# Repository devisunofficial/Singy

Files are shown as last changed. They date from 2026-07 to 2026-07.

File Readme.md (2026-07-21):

# Singy

This is an mp3 player I build because I wanted a mp3 player because having an MP3 player seems cool but not wanted to buy one.
It is inspired from iPod but it is not that good(I never had iPod). I just find Screen and Circular Controller a nice design.

### Features:

 - Minimilist. Just a display and Trackpad
 - 2.8 inch non touch display
 - Circular trackpad (but no haptics) {for me adding haptics is too much}
 - Have Wifi, Bluetooth and 3.5mm Headphone Jack (but I will only use 3.5mm Jack)
 - Inbuilt DAC and AMP (I hope it has good sound quality)

### CAD Model:
Everything fits together using Glue.

It has 3 separate printed pieces. The BackPanel, the shell , and Front Panel to cover electronics.
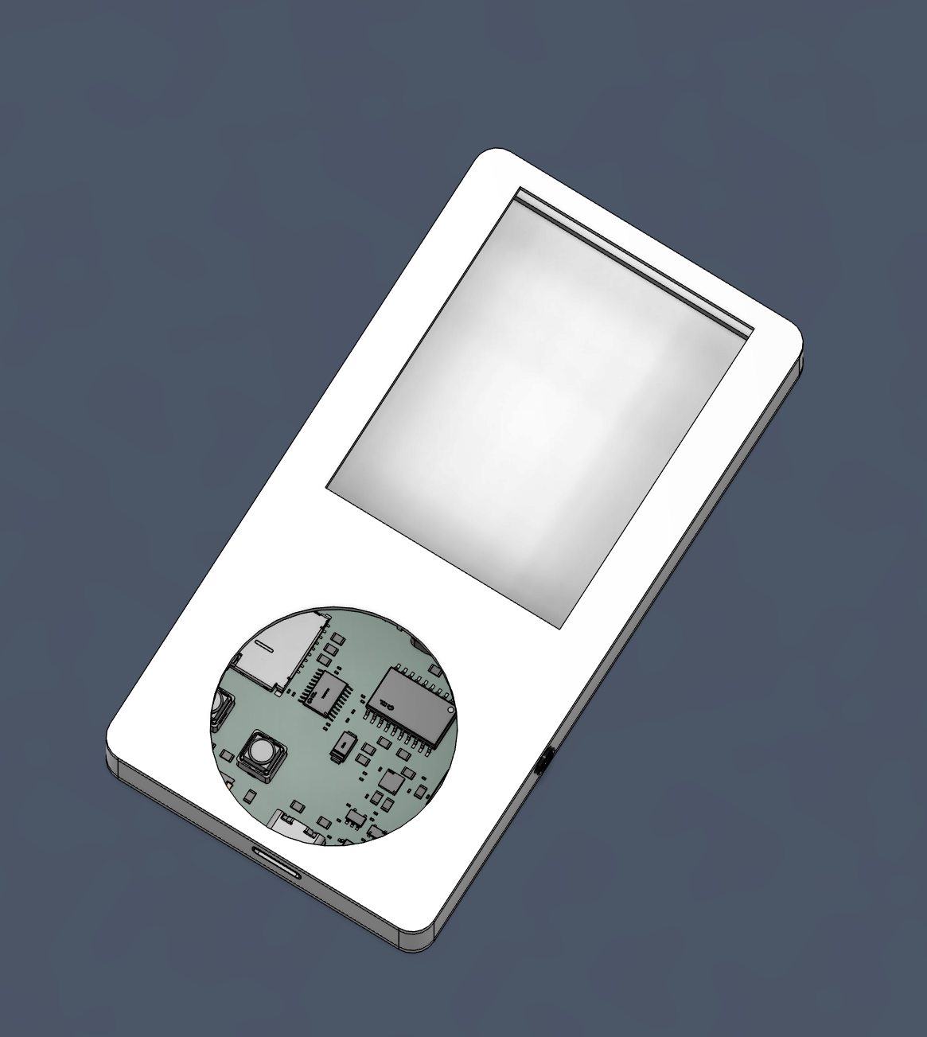
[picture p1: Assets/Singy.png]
Complete Singy


Made in Autodesk Fusion.
I didn't inserted 3D model for Display and Trackpad (Because I can't find)
So I will add this when it is completed!!

### PCB:
Here's my PCB! It was made in KiCad. 

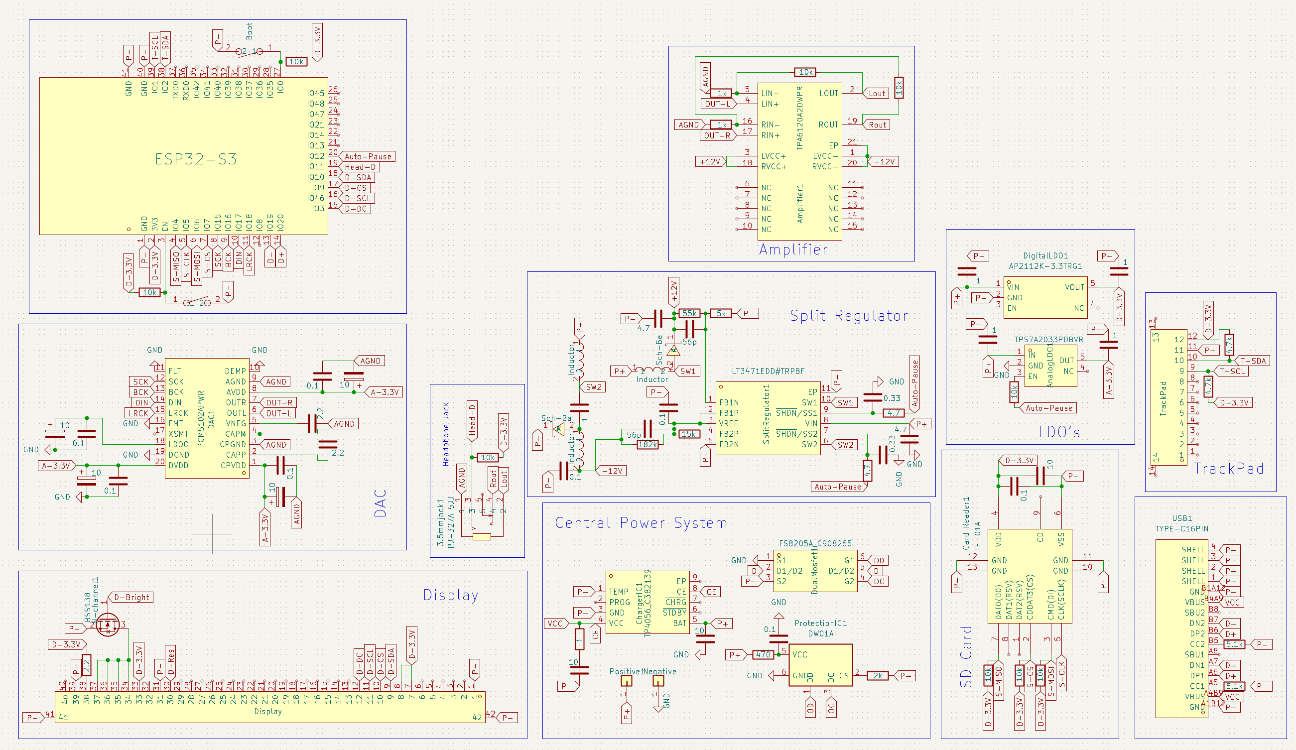
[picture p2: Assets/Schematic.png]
Schematic : 
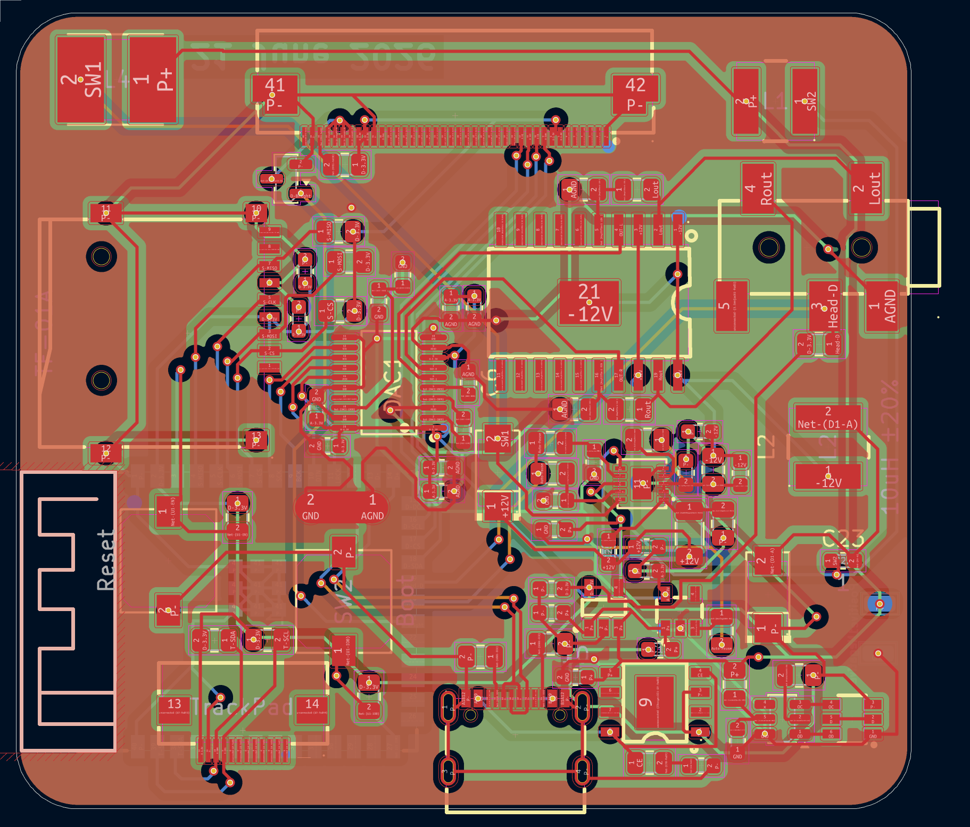
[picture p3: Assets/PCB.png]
PCB Footprint : 

### Firmware Overview:
Currently Firmware is underdevelopment so there is some time to finished product.
This MP3 player uses CPP for firmware.
Features after completion:
 - Three ways to add new songs
    1. Directly in SD-Card
    2. Through USB Port
    3. Over Wi-fi.
 - The most important feature is it is offline but the Library is always updated
 - In final version, you need to save some of your favourite songs, and at your preferred date and time library will be updated.(Might need a server or device that has wifi and can run continously for this) 

 I might add more in the future! That's the only plan I have now

### BOM Table:
|S. No.|Name|Use|Quantity|
|---|----|---|---|
|1|PCB|Main Circuit|1|
|2|ESP32-S3 Wroom 1|Microcontroller|1|
|3|2.8inch Display|Display|1|
|4|Cirque TrackPad|Controlling and Navigation|1|
|5|Battery|Power Source |1|

### Assembly Instructions:
1. Flash PCB with Firmware, connect everything and check if everything is working or not
2. If Everything works, stick battery and PCB to their Respective places.
3. Also Stick Display and TrackPad Carefully to their places
4. Sltick all bodies together and Voila you have an MP3 player

### Extra Stuff:
 Not anything for now but I will surely have when the build is complete.

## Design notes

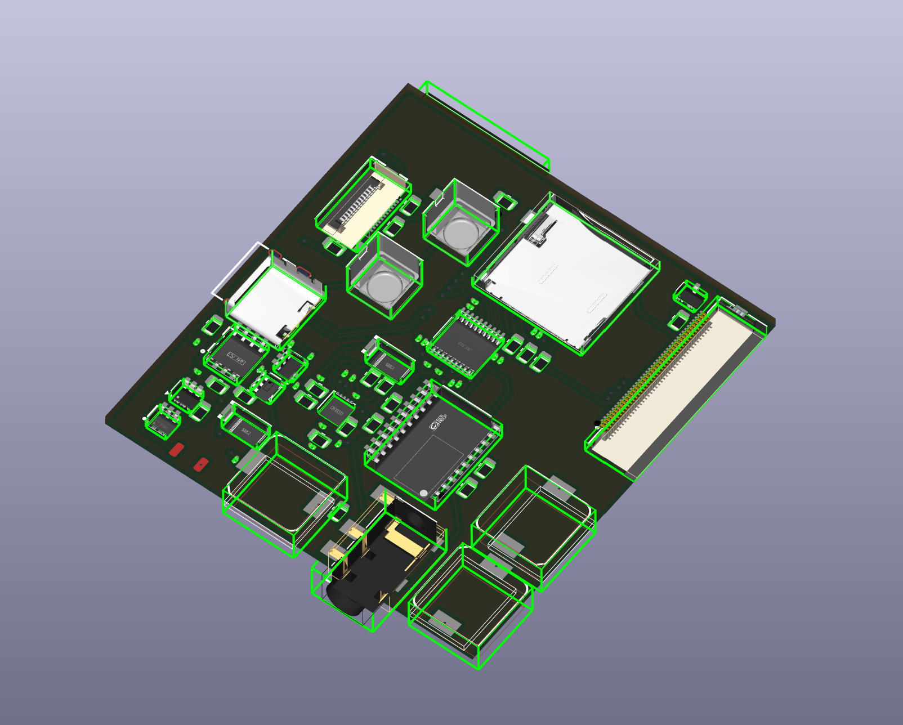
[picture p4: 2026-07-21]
Assets/PCB_CAD-Front.png

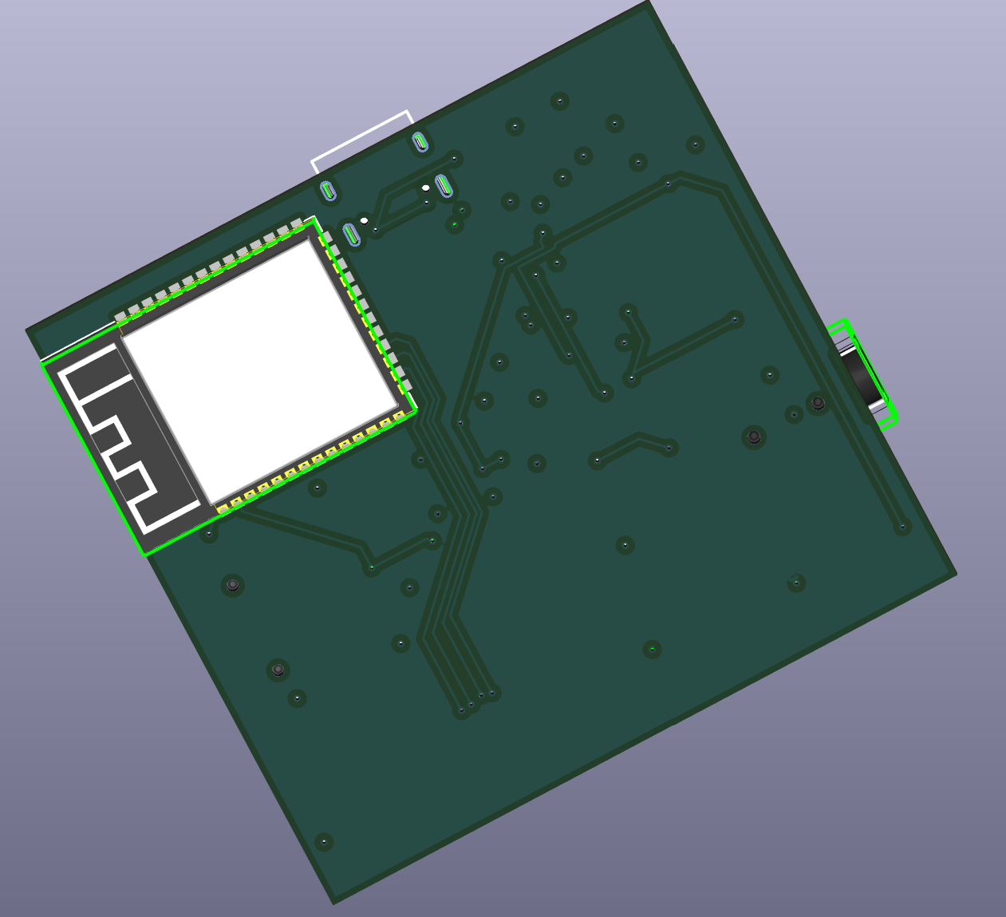
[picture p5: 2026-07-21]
Assets/PCB_CAD-Back.png

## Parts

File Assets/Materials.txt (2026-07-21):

1. ESP32-S3-WROOM-1-N16R8          (Brain)
2. PCM5102APWR (TI)                (DAC)
3. TPA6120A2DWPR (TI)              (Amplifier)
4. AP2112K-3.3TRG1                 (Digital LDO)
5. TPS7A2033PDBVR (TI)             (Analog LDO)
6. LT3471EDD#TRPBF (TI)            (Split Regulator)
7. MicroSD Slot                    (Push-Push type)
8. Audio Jack                      (Female)
9. 16-pin USB-C Female Connector   (Power and Flashing)
10. TP4056                         (Charger IC)
11. DW01A                          (Protection IC)
12. FS8205A                        (Dual MOSFETS)
13. BSS138                         (N-Channel MOSFET)
14. NHD-2.8-240320AF-CSXP-F        (Display)
15. TM035035-2024-003              (Trackpad)

955465-3.7v 5000mAh Rechargeable Battery for Power Bank DVD, Tablet, MP3 Player, GPS, Instruments and DIY 5000 mah 
https://www.amazon.in/955465-3-7v-Rechargeable-Power-Bank-5000/dp/B0H2MS8Z9L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

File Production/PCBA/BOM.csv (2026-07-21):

Comment | Designator | Footprint
PJ-327A 5JJ | 3.5mmjack1 | AUDIO-SMD_PJ-327A5JJ
TPA6120A2DWPR | Amplifier1 | HSOP-20_L12.9-W7.5-P1.27-BL-EP
TPS7A2033PDBVR | AnalogLDO1 | SOT-23-5_L2.9-W1.6-P0.95-LS2.8-BR
2.2 | C1, C6 | C_0603_1608Metric
0.1 | C2, C5, C8, C9, C20, C21, C24, C26 | C_0603_1608Metric
10 | C3, C4, C7, C10, C18, C19, C27 | C_0603_1608Metric
1 | C11, C12, C13, C14, C23 | C_0603_1608Metric
0.33 | C15, C17 | C_0603_1608Metric
4.7 | C16, C28 | C_0603_1608Metric
56p | C22, C25 | C_0603_1608Metric
TF-01A | Card_Reader1 | TF-SMD_TF-01A
TP4056_C382139 | ChargerIC1 | ESOP-8_L4.9-W3.9-P1.27-LS6.0-BL-EP
Sch-Ba | D1, D2 | SMA_L4.4-W2.6-LS5.0-RD
PCM5102APWR | DAC1 | TSSOP-20_L6.5-W4.4-P0.65-LS6.4-BL
AP2112K-3.3TRG1 | DigitalLDO1 | SOT-25-5_L2.9-W1.6-P0.95-LS2.8-BL
FS8205A_C908265 | DualMosfet1 | SOT-23-6_L2.9-W1.6-P0.95-LS2.8-BR
Display | FPC1 | FFC-SMD_541324062
10uH ±20% | L1, L2 | C9389_IND-SMD_2P-L5_0-W5_0
10uH ±20% | L4 | C9164_IND-SMD_L5_8-W5_2
BSS138 | N-channel1 | SOT-23
DW01A | ProtectionIC1 | SOT-23-6
4.7 | R1, R2 | R_0805_2012Metric
1 | R3 | R_0805_2012Metric
2k | R4 | R_0805_2012Metric
470 | R5 | R_0805_2012Metric
15k | R6 | R_0805_2012Metric
182k | R7 | R_0805_2012Metric
55k | R8 | R_1206_3216Metric
5k | R9 | R_0805_2012Metric
10k | R10, R11, R12, R14, R18, R19, R20, R23, R24 | R_0805_2012Metric
5.1k | R13, R25 | R_0805_2012Metric
4.7k | R15, R16 | R_0805_2012Metric
2.2 | R17 | R_0805_2012Metric
1k | R21, R22 | R_0805_2012Metric
LT3471EDD#TRPBF | SplitRegulator1 | DFN-10_L3.0-W3.0-P0.50-BL-EP
Boot | SW2 | SW-SMD_L6.0-W6.0-LS6.6
Reset | SW3 | SW-SMD_L6.0-W6.0-LS6.6
TrackPad | U2 | FPC-SMD_12P-P0.50_HC-FPC-0.5-12P-FH20
TYPE-C16PIN | USB1 | USB-C-SMD_TYPE-C16PIN

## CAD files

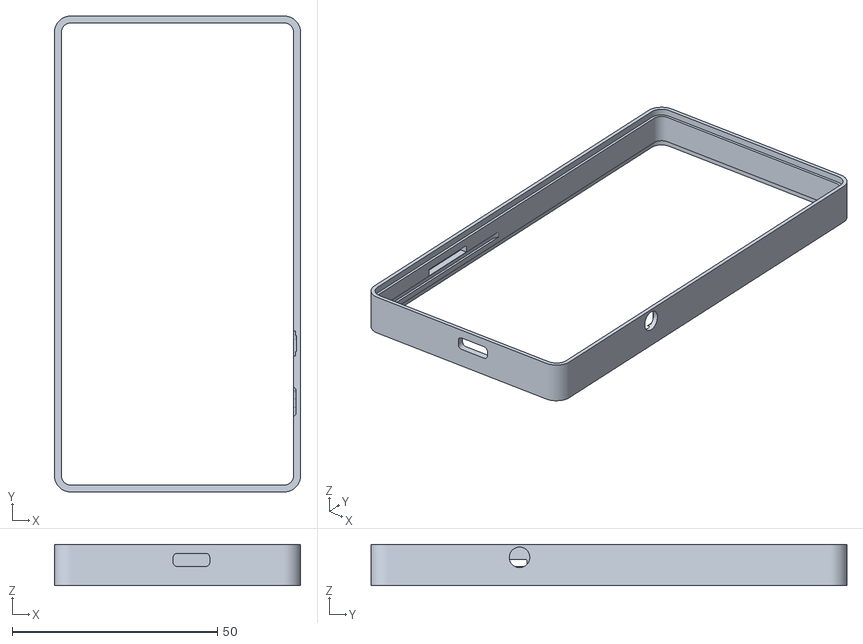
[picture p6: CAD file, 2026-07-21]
Production/3D-Parts/Shell.stl
60.0 x 116.0 x 10.0

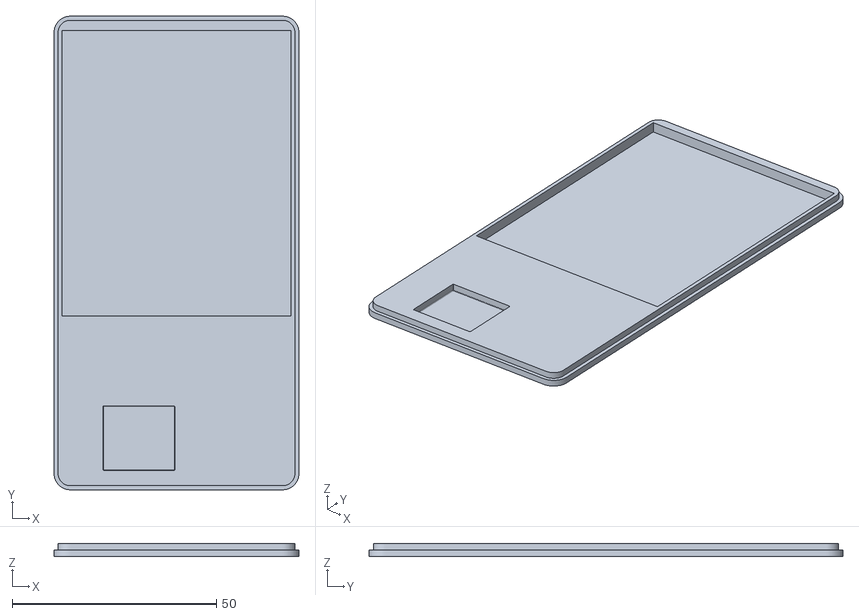
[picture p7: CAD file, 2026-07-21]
Production/3D-Parts/BackPanel.stl
60.0 x 116.0 x 3.20

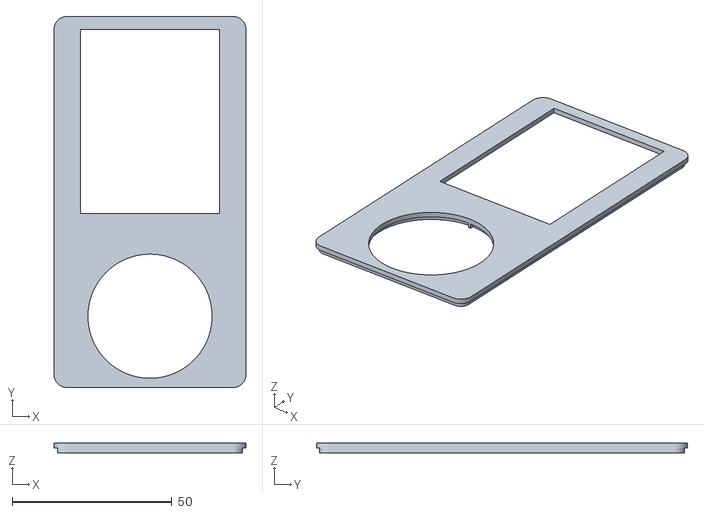
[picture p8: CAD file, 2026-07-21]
Production/3D-Parts/FrontPanel.stl
60.0 x 116.0 x 3.20

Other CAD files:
Step-Files/Shell.step
Step-Files/BackPanel.step
Step-Files/FrontPanel.step

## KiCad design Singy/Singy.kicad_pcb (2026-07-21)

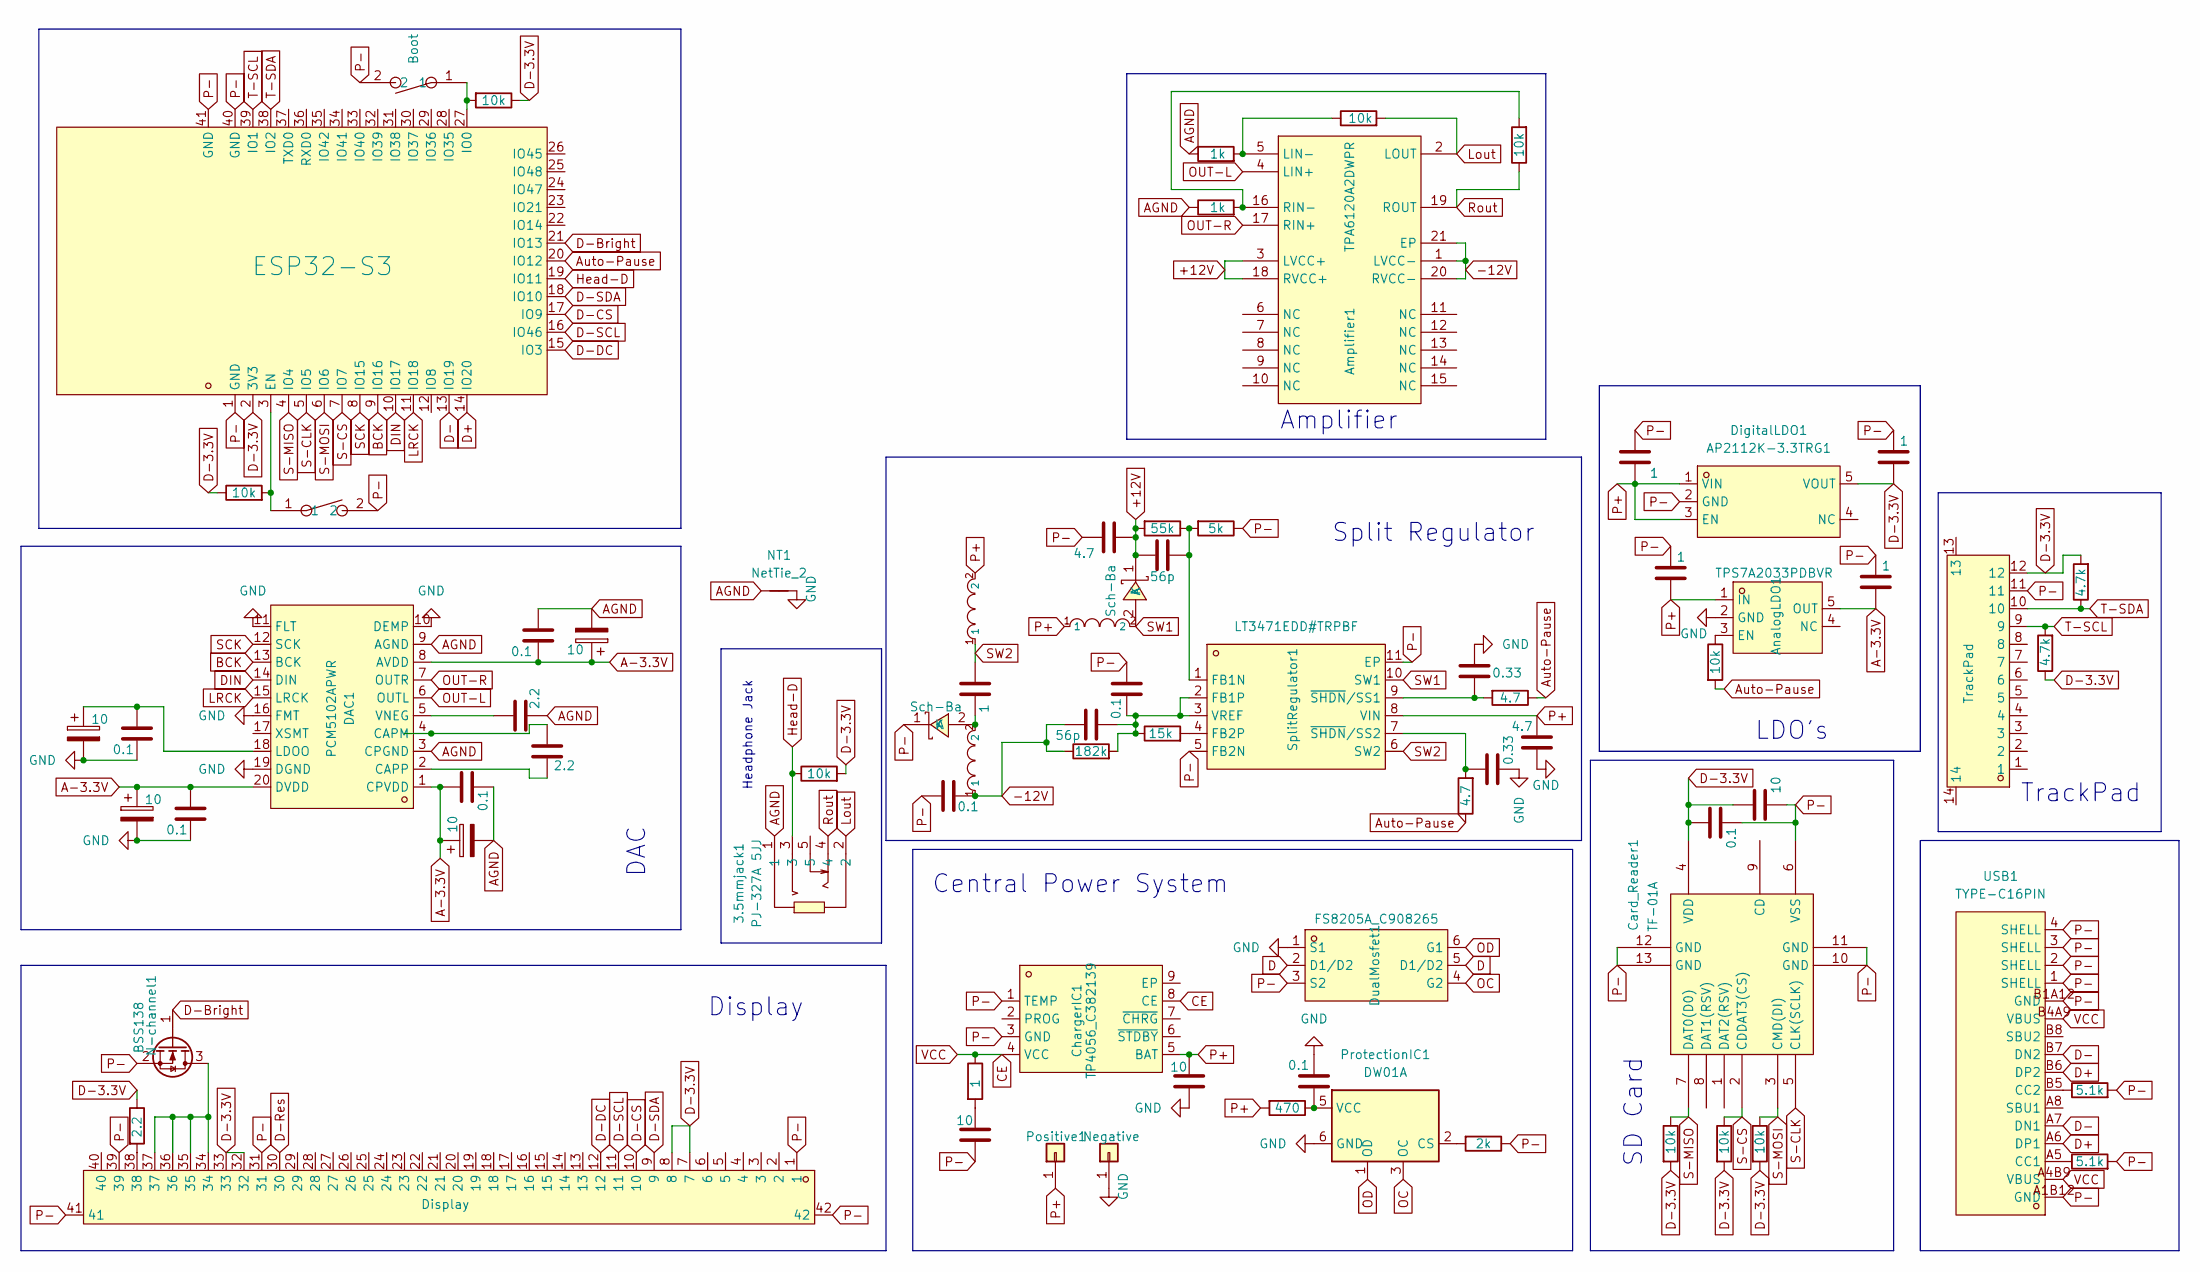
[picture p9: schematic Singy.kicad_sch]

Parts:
3.5mmjack1: PJ-327A 5JJ; AUDIO-SMD_PJ-327A5JJ; MPN PJ-327A 5JJ; LCSC Part C668605
Amplifier1: TPA6120A2DWPR; HSOP-20_L12.9-W7.5-P1.27-BL-EP; MPN TPA6120A2DWPR; LCSC Part C70439
AnalogLDO1: TPS7A2033PDBVR; SOT-23-5_L2.9-W1.6-P0.95-LS2.8-BR; MPN TPS7A2033PDBVR; LCSC Part C2862740
C1, C6: 2.2; C_0603_1608Metric
C2, C5, C8, C9, C20, C21, C24, C26: 0.1; C_0603_1608Metric
C3, C4, C7, C10, C18, C19, C27: 10; C_0603_1608Metric
C11, C12, C13, C14, C23: 1; C_0603_1608Metric
C15, C17: 0.33; C_0603_1608Metric
C16, C28: 4.7; C_0603_1608Metric
C22, C25: 56p; C_0603_1608Metric
Card_Reader1: TF-01A; TF-SMD_TF-01A; MPN TF-01A; LCSC Part C91145
ChargerIC1: TP4056_C382139; ESOP-8_L4.9-W3.9-P1.27-LS6.0-BL-EP; MPN TP4056; LCSC Part C382139
D1, D2: Sch-Ba; SMA_L4.4-W2.6-LS5.0-RD; MPN B230A-13-F; LCSC Part C12889
DAC1: PCM5102APWR; TSSOP-20_L6.5-W4.4-P0.65-LS6.4-BL; MPN PCM5102APWR; LCSC Part C107671
DigitalLDO1: AP2112K-3.3TRG1; SOT-25-5_L2.9-W1.6-P0.95-LS2.8-BL; MPN AP2112K-3.3TRG1; LCSC Part C51118
DualMosfet1: FS8205A_C908265; SOT-23-6_L2.9-W1.6-P0.95-LS2.8-BR; MPN FS8205A; LCSC Part C908265
FPC1: Display; FFC-SMD_541324062; MPN 541324062; LCSC Part C505102
J2: Negative; SolderWirePad_1x01_SMD_1x2mm
L1, L2: 10uH ±20%; C9389_IND-SMD_2P-L5_0-W5_0; LCSC C9389
L4: 10uH ±20%; C9164_IND-SMD_L5_8-W5_2; LCSC C9164
N-channel1: BSS138; SOT-23
NT1: NetTie_2; NetTie-2_SMD_Pad2.0mm
Positive1: Conn_01x01; SolderWirePad_1x01_SMD_1x2mm
ProtectionIC1: DW01A; SOT-23-6
R1, R2: 4.7; R_0805_2012Metric
R3: 1; R_0805_2012Metric
R4: 2k; R_0805_2012Metric
R5: 470; R_0805_2012Metric
R6: 15k; R_0805_2012Metric
R7: 182k; R_0805_2012Metric
R8: 55k; R_1206_3216Metric
R9: 5k; R_0805_2012Metric
R10, R11, R12, R14, R18, R19, R20, R23, R24: 10k; R_0805_2012Metric
R13, R25: 5.1k; R_0805_2012Metric
R15, R16: 4.7k; R_0805_2012Metric
R17: 2.2; R_0805_2012Metric
R21, R22: 1k; R_0805_2012Metric
SW2: Boot; SW-SMD_L6.0-W6.0-LS6.6; MPN SPEH110100; LCSC Part C97448
SW3: Reset; SW-SMD_L6.0-W6.0-LS6.6; MPN SPEH110100; LCSC Part C97448
SplitRegulator1: LT3471EDD#TRPBF; DFN-10_L3.0-W3.0-P0.50-BL-EP; MPN LT3471EDD#TRPBF; LCSC Part C514422
U1: ESP32-S3; WIRELM-SMD_ESP32-S3-WROOM-1; MPN ESP32-S3-WROOM-1-N16R8; LCSC Part C2913202
U2: TrackPad; FPC-SMD_12P-P0.50_HC-FPC-0.5-12P-FH20; MPN HC-FPC-0.5-12P-FH20; LCSC Part C19273928
USB1: TYPE-C16PIN; USB-C-SMD_TYPE-C16PIN; MPN TYPE-C16PIN; LCSC Part C393939

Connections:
+12V: Amplifier1.3 (LVCC+), Amplifier1.18 (RVCC+), C25.2, C28.1, D2.1 (K), R8.2
-12V: Amplifier1.1 (LVCC-), Amplifier1.20 (RVCC-), Amplifier1.21 (EP), C22.1, C24.2, L2.1, R7.1
A-3.3V: AnalogLDO1.5 (OUT), C2.1, C3.1, C4.1, C5.1, C7.1, C8.1, C14.2, DAC1.1 (CPVDD), DAC1.8 (AVDD), DAC1.20 (DVDD)
AGND: 3.5mmjack1.1, C2.2, C3.2, C4.2, C5.2, C6.1, DAC1.3 (CPGND), DAC1.9 (AGND), NT1.1, R21.1, R22.1
Auto-Pause: R1.1, R2.1, R14.2, U1.20 (IO12)
BCK: DAC1.13 (BCK), U1.9 (IO16)
CE: ChargerIC1.4 (VCC), ChargerIC1.8 (CE), R3.1, USB1.A4B9 (VBUS), USB1.B4A9 (VBUS)
D: DualMosfet1.2 (D1/D2), DualMosfet1.5 (D1/D2)
D+: U1.14 (IO20), USB1.A6 (DP1), USB1.B6 (DP2)
D-: U1.13 (IO19), USB1.A7 (DN1), USB1.B7 (DN2)
D-3.3V: C11.2, C26.1, C27.1, Card_Reader1.4 (VDD), DigitalLDO1.5 (VOUT), FPC1.7, FPC1.8, FPC1.32, FPC1.33, R10.2, R15.1, R16.2, R17.1, R18.2, R19.2, R20.2, R23.1, R24.1, U1.2 (3V3), U2.12
D-Bright: N-channel1.1 (G), U1.21 (IO13)
D-CS: FPC1.10, U1.17 (IO9)
D-DC: FPC1.12, U1.15 (IO3)
D-Res: FPC1.30
D-SCL: FPC1.11, U1.16 (IO46)
D-SDA: FPC1.9, U1.18 (IO10)
DIN: DAC1.14 (DIN), U1.10 (IO17)
GND: AnalogLDO1.2 (GND), C7.2, C8.2, C9.2, C10.2, C15.2, C16.1, C17.2, C19.2, C20.1, DAC1.10 (DEMP), DAC1.11 (FLT), DAC1.16 (FMT), DAC1.19 (DGND), DualMosfet1.1 (S1), J2.1 (Pin_1_1), NT1.2, ProtectionIC1.6 (GND)
Head-D: 3.5mmjack1.3, R10.1, U1.19 (IO11)
LRCK: DAC1.15 (LRCK), U1.11 (IO18)
Lout: 3.5mmjack1.2, Amplifier1.2 (LOUT), R12.2
unnamed: Amplifier1.5 (LIN-), R12.1, R21.2
unnamed: Amplifier1.16 (RIN-), R11.2, R22.2
unnamed: AnalogLDO1.3 (EN), R14.1
unnamed: C18.1, R3.2
unnamed: C23.2, D1.2 (A), L2.2
unnamed: C1.2, DAC1.4 (CAPM)
unnamed: C1.1, DAC1.2 (CAPP)
unnamed: C9.1, C10.1, DAC1.18 (LDOO)
unnamed: C6.2, DAC1.5 (VNEG)
unnamed: FPC1.38, R17.2
unnamed: FPC1.34, FPC1.35, FPC1.36, FPC1.37, N-channel1.3 (D)
unnamed: ProtectionIC1.2 (CS), R4.2
unnamed: C20.2, ProtectionIC1.5 (VCC), R5.1
unnamed: C25.1, R8.1, R9.2, SplitRegulator1.1 (FB1N)
unnamed: C21.2, C22.2, R6.1, R7.2, SplitRegulator1.2 (FB1P), SplitRegulator1.3 (VREF)
unnamed: R6.2, SplitRegulator1.4 (FB2P)
unnamed: C15.1, R1.2, SplitRegulator1.9 (~SHDN/SS1)
unnamed: C17.1, R2.2, SplitRegulator1.7 (~SHDN/SS2)
unnamed: R24.2, SW3.1, U1.3 (EN)
unnamed: R23.2, SW2.1, U1.27 (IO0)
unnamed: R25.1, USB1.A5 (CC1)
unnamed: R13.1, USB1.B5 (CC2)
OC: DualMosfet1.4 (G2), ProtectionIC1.3 (OC)
OD: DualMosfet1.6 (G1), ProtectionIC1.1 (OD)
OUT-L: Amplifier1.4 (LIN+), DAC1.6 (OUTL)
OUT-R: Amplifier1.17 (RIN+), DAC1.7 (OUTR)
P+: AnalogLDO1.1 (IN), C12.2, C13.2, C16.2, C19.1, ChargerIC1.5 (BAT), DigitalLDO1.1 (VIN), DigitalLDO1.3 (EN), L1.2, L4.1, Positive1.1 (Pin_1_1), R5.2, SplitRegulator1.8 (VIN)
P-: C11.1, C12.1, C13.1, C14.1, C18.2, C21.1, C24.1, C26.2, C27.2, C28.2, Card_Reader1.6 (VSS), Card_Reader1.10 (GND), Card_Reader1.11 (GND), Card_Reader1.12 (GND), Card_Reader1.13 (GND), ChargerIC1.1 (TEMP), ChargerIC1.3 (GND), D1.1 (K), DigitalLDO1.2 (GND), DualMosfet1.3 (S2), FPC1.1, FPC1.31, FPC1.39, FPC1.41, FPC1.42, N-channel1.2 (S), R4.1, R9.1, R13.2, R25.2, SW2.2, SW3.2, SplitRegulator1.5 (FB2N), SplitRegulator1.11 (EP), U1.1 (GND), U1.40 (GND), U1.41 (GND), U2.11, USB1.1 (SHELL), USB1.2 (SHELL), USB1.3 (SHELL), USB1.4 (SHELL), USB1.A1B12 (GND), USB1.B1A12 (GND)
Rout: 3.5mmjack1.4, Amplifier1.19 (ROUT), R11.1
S-CLK: Card_Reader1.5 (CLK(SCLK)), U1.5 (IO5)
S-CS: Card_Reader1.2 (CDDAT3(CS)), R18.1, U1.7 (IO7)
S-MISO: Card_Reader1.7 (DAT0(D0)), R20.1, U1.4 (IO4)
S-MOSI: Card_Reader1.3 (CMD(DI)), R19.1, U1.6 (IO6)
SCK: DAC1.12 (SCK), U1.8 (IO15)
SW1: D2.2 (A), L4.2, SplitRegulator1.10 (SW1)
SW2: C23.1, L1.1, SplitRegulator1.6 (SW2)
T-SCL: R15.2, U1.39 (IO1), U2.9
T-SDA: R16.1, U1.38 (IO2), U2.10

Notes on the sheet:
LDO's
Amplifier
Central Power System
TrackPad
Display
Split Regulator
SD Card
Headphone Jack
DAC

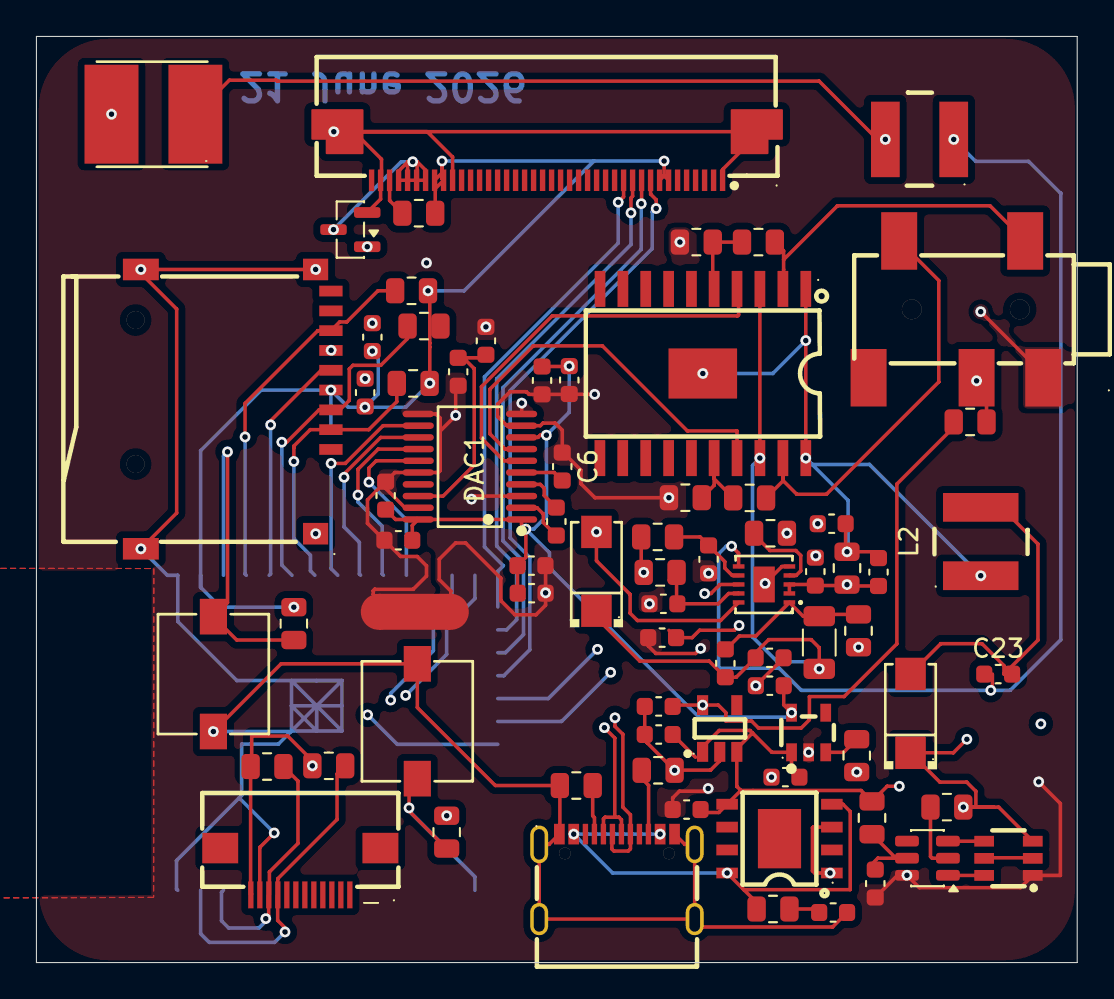
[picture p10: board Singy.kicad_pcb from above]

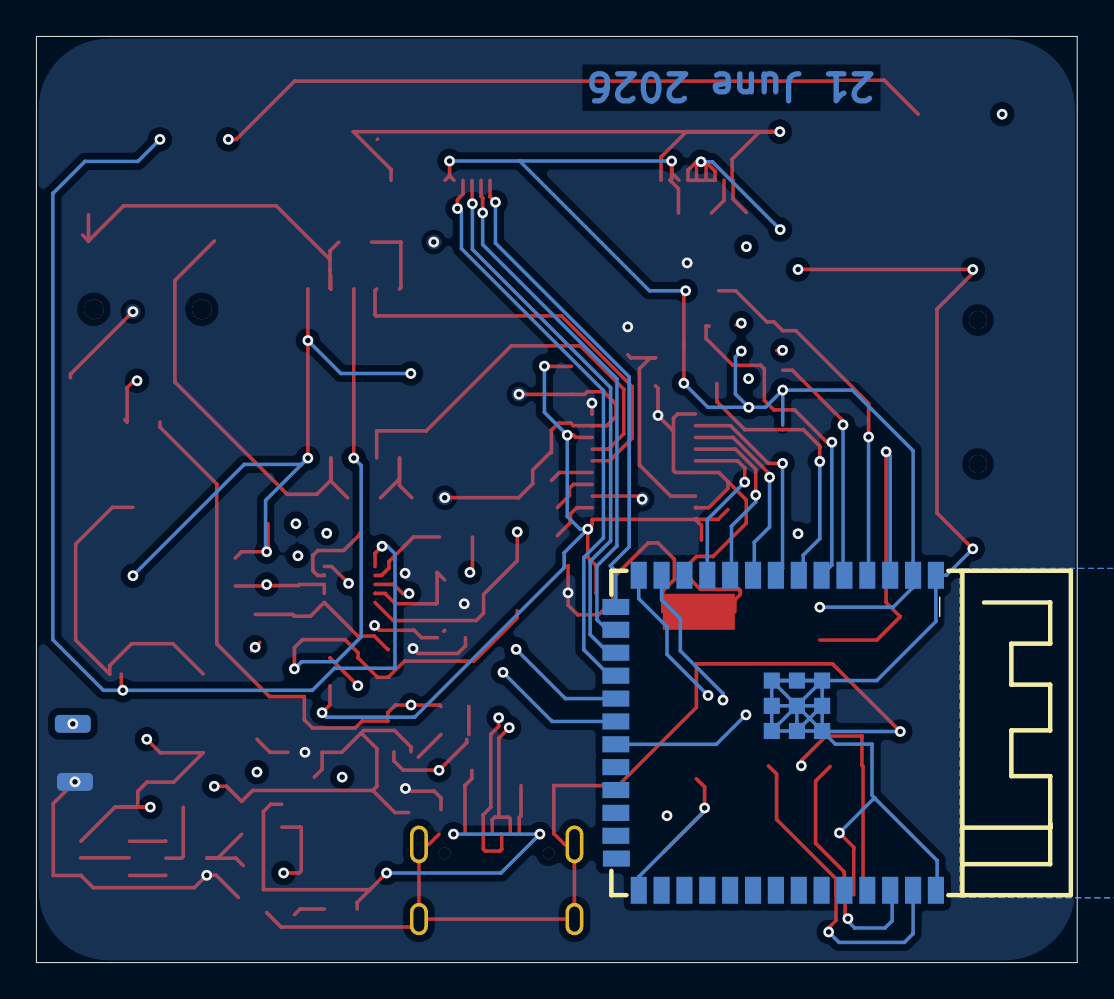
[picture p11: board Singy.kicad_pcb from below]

Board: 4 copper layers, 57.8 x 51.5 mm, 78 parts (3 on the bottom side), 59 nets.

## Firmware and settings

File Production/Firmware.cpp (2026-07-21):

#include "Arduino.h"
#include "Audio.h"
#include "SD.h"
#include "SPI.h"
#include "Wire.h"

#define SD_MISO_PIN     4
#define SD_MOSI_PIN     6
#define SD_SCK_PIN      5
#define SD_CS_PIN       7

#define I2S_BCLK_PIN     5
#define I2S_LRCK_PIN     6
#define I2S_DOUT_PIN     7

#define HP_DETECT_PIN    19  
#define AUTO_PAUSE_PIN   20  

#define I2C_SDA_PIN      38
#define I2C_SCL_PIN      39
#define CIRQUE_I2C_ADDR  0x2A 

Audio audio;
bool headphoneConnected = false;
int currentVolume = 12;         
unsigned long lastTrackpadPoll = 0;
const int pollInterval = 30;   

struct TrackpadData {
    bool valid;
    bool touchDown;
    int8_t deltaX;
    int8_t deltaY;
};


void initTrackpad() {
    Wire.begin(I2C_SDA_PIN, I2C_SCL_PIN, 100000);
    
    
    Wire.beginTransmission(CIRQUE_I2C_ADDR);
    Wire.write(0x05);
    Wire.write(0x00);
    Wire.endTransmission();
    delay(10);
}

TrackpadData readTrackpad() {
    TrackpadData data = {false, false, 0, 0};
    
    byte count = Wire.requestFrom(CIRQUE_I2C_ADDR, 4);
    if (count == 4) {
        byte status = Wire.read();
        data.deltaX = (int8_t)Wire.read();
        data.deltaY = (int8_t)Wire.read();
        Wire.read();
        
        data.touchDown = (status & 0x01); 
        data.valid = true;
    }
    return data;
}

// Manage Trackpad Inputs to Change Tracks/Volume
void handleNavigation() {
    if (millis() - lastTrackpadPoll < pollInterval) return;
    lastTrackpadPoll = millis();

    TrackpadData pad = readTrackpad();
    if (!pad.valid || !pad.touchDown) return;

    // Volume Adjustment via Vertical Swipe (Y-Axis Threshold)
    if (pad.deltaY > 15) {
        if (currentVolume < 21) {
            currentVolume++;
            audio.setVolume(currentVolume);
            Serial.printf("Volume Up: %d\n", currentVolume);
        }
    } else if (pad.deltaY < -15) {
        if (currentVolume > 0) {
            currentVolume--;
            audio.setVolume(currentVolume);
            Serial.printf("Volume Down: %d\n", currentVolume);
        }
    }
    if (pad.deltaX > 25) {
        Serial.println("Trackpad Gestured: Next Track Triggered");
    } else if (pad.deltaX < -25) {
        Serial.println("Trackpad Gestured: Previous Track Triggered");
    }
}

void handleHeadphoneState() {
    bool currentJackState = (digitalRead(HP_DETECT_PIN) == HIGH);

    if (currentJackState != headphoneConnected) {
        headphoneConnected = currentJackState;

        if (headphoneConnected) {
            Serial.println("🎧 Headphones Plugged In! Enabling Analog Stage...");
            
            digitalWrite(AUTO_PAUSE_PIN, HIGH); 
            delay(50); 
            
            if (!audio.isRunning()) {
                audio.pauseResume(); 
            }
        } 
        else {
            Serial.println("🔇 Headphones Disconnected! Entering Auto-Pause Mode...");
            
            if (audio.isRunning()) {
                audio.pauseResume(); 
            }
            
            digitalWrite(AUTO_PAUSE_PIN, LOW); 
        }
    }
}

void setup() {
    Serial.begin(115200);

    pinMode(HP_DETECT_PIN, INPUT); 
    pinMode(AUTO_PAUSE_PIN, OUTPUT);
    
    digitalWrite(AUTO_PAUSE_PIN, LOW);

    SPI.begin(SD_SCK_PIN, SD_MISO_PIN, SD_MOSI_PIN, SD_CS_PIN);
    if (!SD.begin(SD_CS_PIN)) {
        Serial.println("Error: MicroSD Card Mount Failed!");
        while (true);
    }
    Serial.println("MicroSD Mounted Successfully.");

    initTrackpad();

    audio.setPinout(I2S_BCLK_PIN, I2S_LRCK_PIN, I2S_DOUT_PIN);
    audio.setVolume(currentVolume);

    headphoneConnected = (digitalRead(HP_DETECT_PIN) == HIGH);
    if (headphoneConnected) {
        digitalWrite(AUTO_PAUSE_PIN, HIGH);
        Serial.println("Booting System: Audio Stage Enabled.");
    }

    audio.connecttoFS(SD, "/music.mp3");
}

void loop() {
    if (headphoneConnected) {
        audio.loop();
    }

    handleHeadphoneState();

    handleNavigation();
}

void audio_info(const char *info) {
    Serial.printf("Audio Engine Update: %s\n", info);
}
